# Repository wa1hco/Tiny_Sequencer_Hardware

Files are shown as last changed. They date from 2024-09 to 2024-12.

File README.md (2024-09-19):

# Tiny_Sequencer_Hardware
Schematic, Layout, and component files  
KiCad V8 used for schematic and layout  
ATTiny814 microcontroller  
FTDI230 Serial interface  
Surface mount components  
Back side is grouind plane, a few jumpers, and no components  
Connections via 12 pin screw terminal header with 0.1 inch spacing  
- 4 contact closure outputs using AC/DC optoisolators  
- Key input with return
- 6 to 30V DC input and return

Powered by DC or USB  
Programming via UPDI over USB  
Software able to use serial port for communication  
Status LEDs
- 4 sequencer ouptuts,
- 5V,
- Tx serial activity
- Rx serial activity

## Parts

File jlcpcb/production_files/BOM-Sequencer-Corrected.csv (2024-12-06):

Comment | Designator | Footprint | LCSC | Quantity | Description
47p | C1,C5 | C_0603_1608Metric | C1671 | 2 | 50V 47pF C0G ±5% 0603 Multilayer Ceramic Capacitors
6.8u | C2 | C_0603_1608Metric | C338096 | 1 | 10V 6.8uF X5R ±10% 0603 Multilayer Ceramic Capacitors
.1u | C3,C4,C6,C7,C8,C9 | C_0603_1608Metric | C14663 | 5 | 50V 100nF X7R ±10% 0603 Multilayer Ceramic Capacitors
0.33u | C4 | C_0603_1608Metric | C292682 |  | 50V 330nF X7R ±10% 0603 Multilayer Ceramic Capacitors
Red | D1,D2,D3,D4 | LED_0603_1608Metric | C2286 | 4 | -40℃~+85℃ Red 0603 LED Indication
D_Schottky | D10 | D_0603_1608Metric | C143772 | 1 | 40V 450mV@200mA 200mA 0603 Schottky Diodes
MM3Z3V6 | D11,D12,D5 | D_SOD-323 | C891617 | 3 | Independent Type 3.42V~3.78V 200mW 3.6V SOD-323FL Zener Diodes
Green | D6,D7,D8,D9 | LED_0603_1608Metric | C965806 | 4 | 20mA 240mcd 565nm~575nm -20℃~+85℃ Positive Stick Yellow Green 120° 50mW 2.4V 0603 LED
FerriteBead_Small | FB1 | L_0805_2012Metric | C1017 | 1 | 300mΩ ±25% 600Ω@100MHz 0805 Ferrite Beads
Screw_Terminal_01x12 | J1 | TerminalBlock_TE_1-282834-2_1x12_P2.54mm_Horizontal | C5188451 | 1 | Copper Alloy 1x12P Tin 2.54mm 1 1 12 6A -40℃~+105℃ 150V Green 18~24
Header 1x3 | J2 | PinHeader_1x03_P2.54mm_Vertical | C6332196 | 1 | Gold 250V 3A 2.54mm 3P 6mm -40℃~+105℃ 3mm 2.54mm Brass Black Single
USB-C 2.0 16P | J3 | USB_C_Receptacle_G-Switch_GT-USB-7010ASV | C2988369 | 1 | USB 2.0 3A 1 Horizontal attachment 16P Female -40℃~+85℃ Gold Type-C
Conn_01x08_Pin | J4 | PinHeader_1x08_P2.54mm_Vertical | C18078205 | 1 | Gold 1kV 3A 2.5mm 8P 6mm -40℃~+105℃ 3mm 2.54mm Brass Black Single Row 1x8PPin Headers
1K5 | R1,R2,R3,R4 | R_0603_1608Metric | C22843 | 4 | 100mW Thick Film Resistors 75V ±100ppm/℃ ±1% 1.5kΩ 0603 Chip Resistor
1K5 | R5,R6,R7,R8 | R_0603_1608Metric | C23193 | 4 | 100mW Thick Film Resistors 75V ±100ppm/℃ ±1% 510Ω 0603 Chip Resistor
1K | R10,R11,R12,R15,R16,R17,R20 | R_0603_1608Metric | C21190 | 7 | 100mW Thick Film Resistors 75V ±100ppm/℃ ±1% 1kΩ 0603 Chip Resistor
27R | R13,R14,R18,R19 | R_0603_1608Metric | C25190 | 2 | 100mW Thick Film Resistors 75V ±1% ±200ppm/℃ 27Ω 0603 Chip Resistor
5K1 | R18, R19 | R_0603_1608Metric | C23186 | 2 | 100mW Thick Film Resistors 75V ±100ppm/℃ ±1% 5.1kΩ 0603 Chip Resistor
2K2 | R9 | R_0603_1608Metric | C4190 | 1 | 100mW Thick Film Resistors 75V ±100ppm/℃ ±1% 2.2kΩ 0603 Chip Resistor
GAQY212G2S | U2,U3,U4,U5 | SO-4_4.4x3.9mm_P2.54mm | C7435109 | 4 | 1 Form A(SPST-NO) 1.2V 60V 68mΩ 1.8A SOP-4 Solid State Relays (MOS Output)
MC78L05_SOT89 | U6 | SOT-89-3 | C71136 | 1 | 100mA Fixed 5V Positive electrode 30V SOT-89-3 Voltage Regulators
FT230XS | U7 | SSOP-16_3.9x4.9mm_P0.635mm | C69082 | 1 | USB to UART UART SSOP-16-150mil USB Converters
TLP185 | U8 | SOIC-4_4.55x3.7mm_P2.54mm | C17695768 | 1 | 3.75kV 50mA 1 1.25V SOIC-4-175mil Transistor, Photovoltaic Output Optoisolators
ATtiny1616-M | U9 | VQFN-20-1EP_3x3mm_P0.4mm_EP1.7x1.7mm | C507118 | 1 | 16KB 1.8V~5.5V AVR 2KB 20MHz FLASH 18 QFN-20-EP(3x3) Microcontrollers

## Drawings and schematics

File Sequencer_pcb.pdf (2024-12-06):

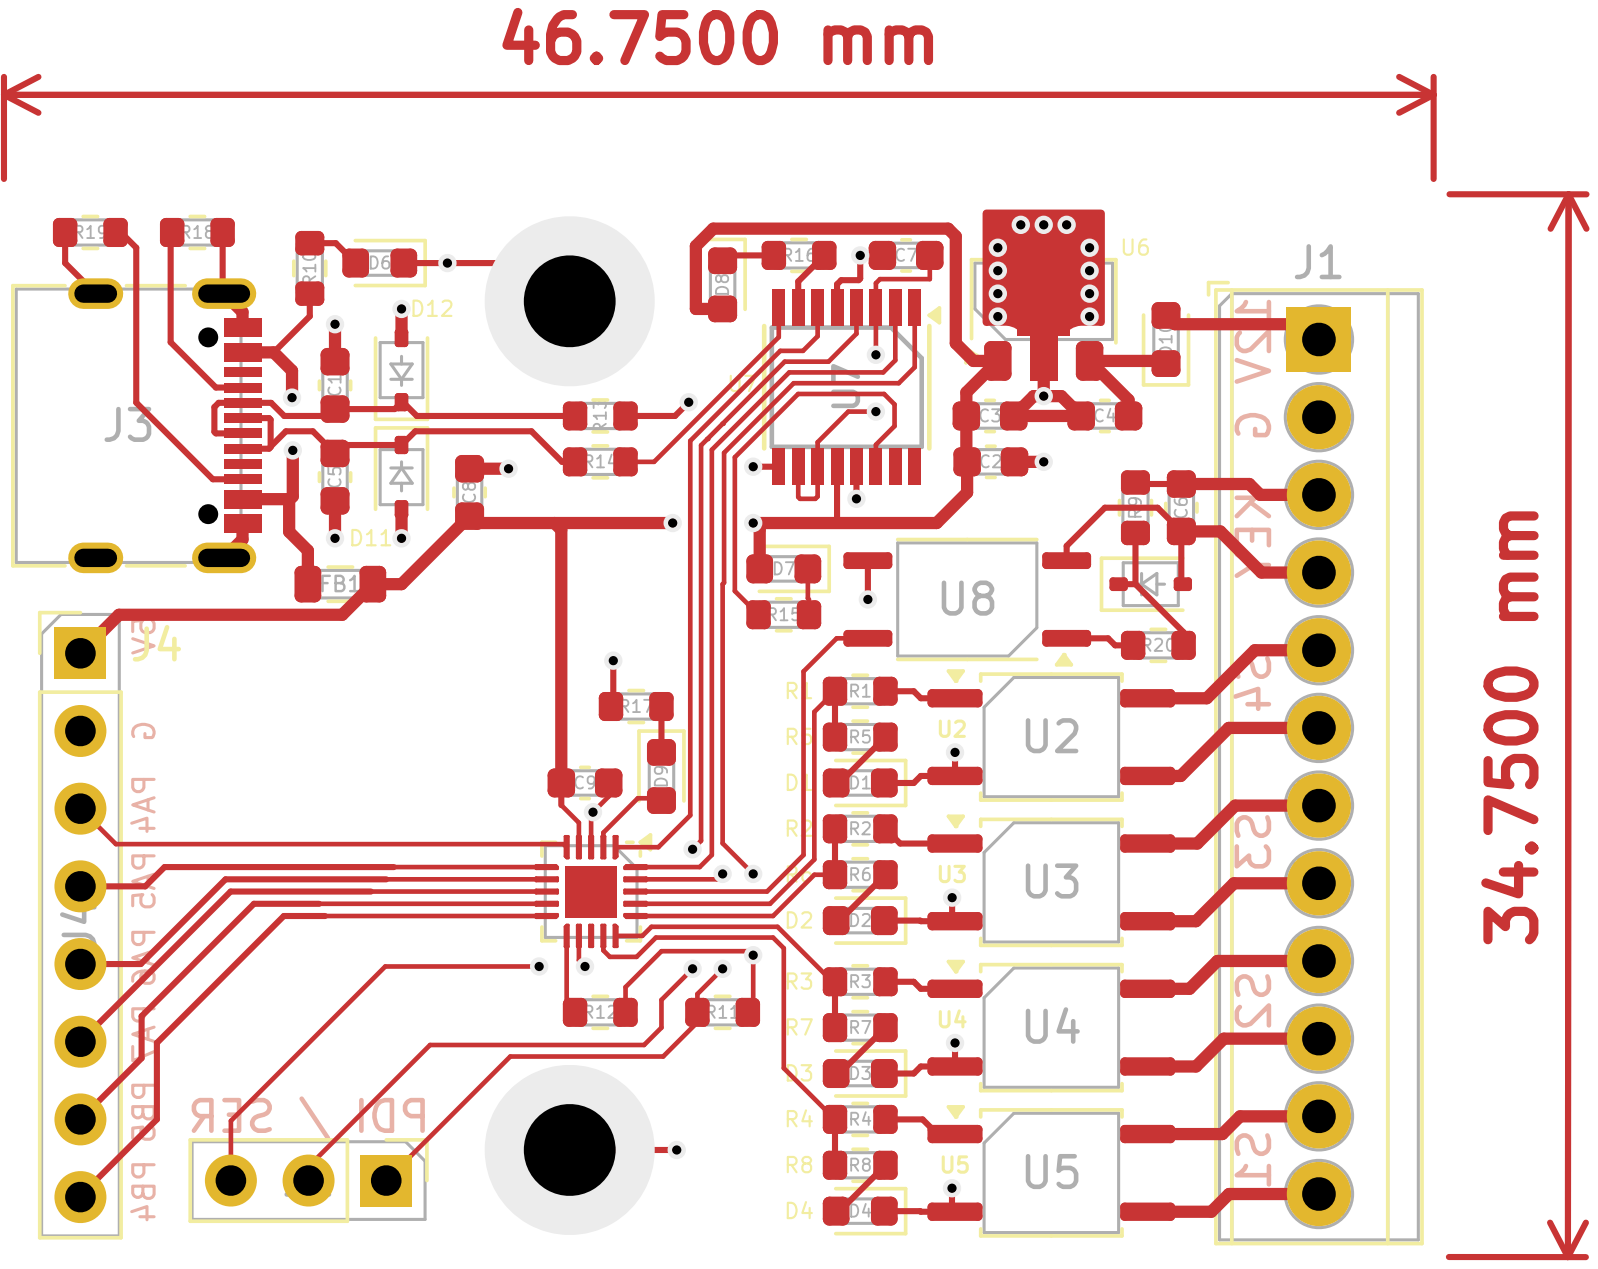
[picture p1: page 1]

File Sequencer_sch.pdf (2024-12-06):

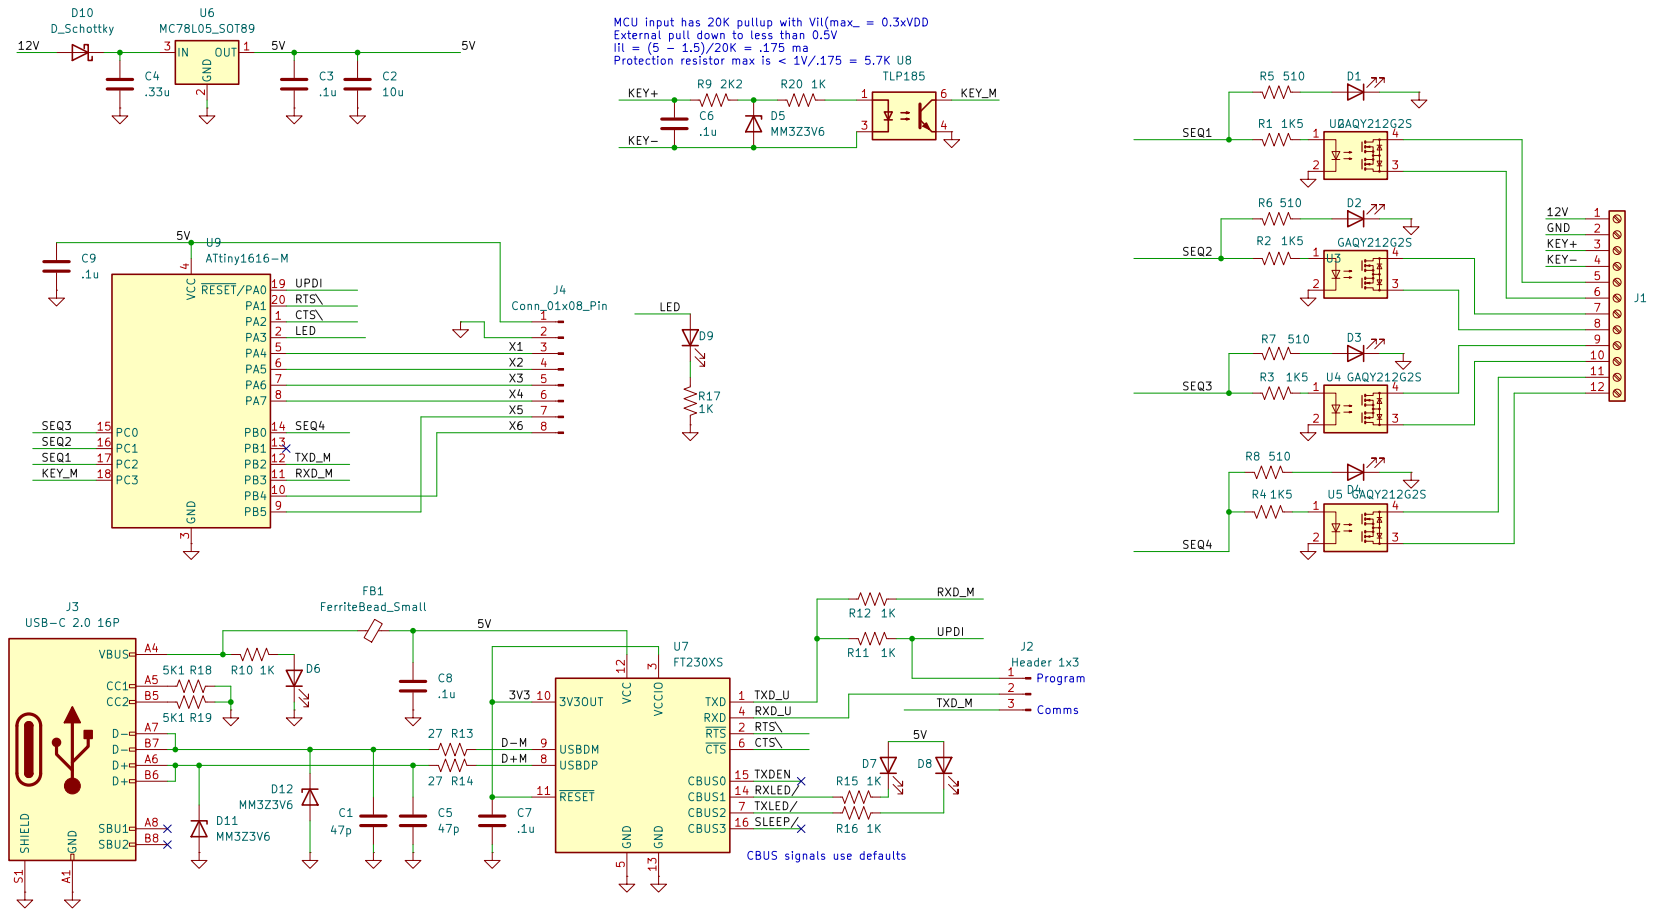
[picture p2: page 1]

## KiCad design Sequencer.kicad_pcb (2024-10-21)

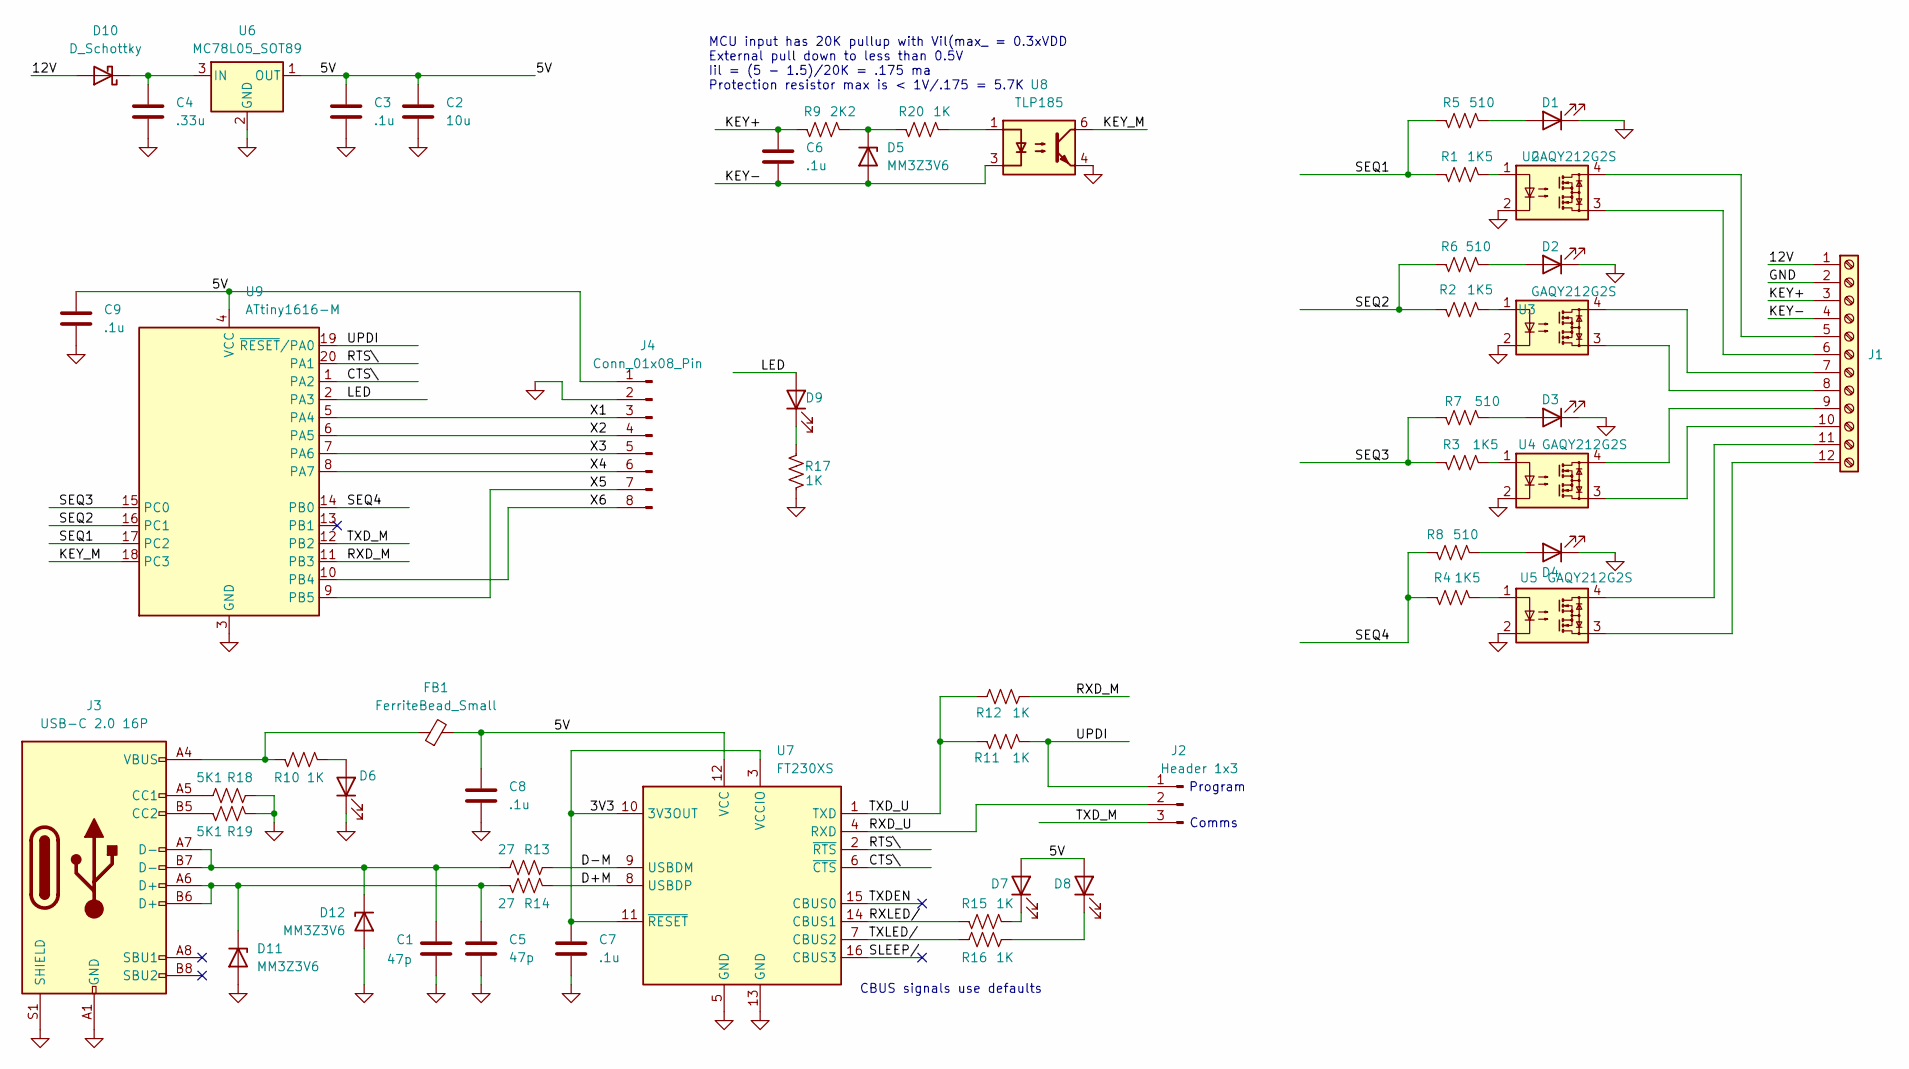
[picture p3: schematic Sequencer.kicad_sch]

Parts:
C1, C5: 47p; C_0603_1608Metric; LCSC PN C1671
C2: 10u; C_0603_1608Metric; LCSC PN C19702
C3, C6, C7, C8, C9: .1u; C_0603_1608Metric; LCSC PN C15849
C4: .33u; C_0603_1608Metric; LCSC PN C2918485
D1, D2, D3, D4: Red; LED_0603_1608Metric; LCSC PN C2286
D5, D11, D12: MM3Z3V6; D_SOD-323; LCSC PN C19077454
D6, D9: Green; LED_0603_1608Metric; LCSC PN C22371299
D7, D8: Yellow; LED_0603_1608Metric; LCSC PN C72038
D10: D_Schottky; D_0603_1608Metric; LCSC PN C143772
FB1: FerriteBead_Small; L_0805_2012Metric; LCSC PN C1017
J1: Screw_Terminal_01x12; TerminalBlock_TE_1-282834-2_1x12_P2.54mm_Horizontal; LCSC PN C474929
J2: Header 1x3; PinHeader_1x03_P2.54mm_Vertical; LCSC PN C6332196
J3: USB-C 2.0 16P; USB_C_Receptacle_G-Switch_GT-USB-7010ASV; LCSC PN C2835315
J4: Conn_01x08_Pin; PinHeader_1x08_P2.54mm_Vertical; LCSC PN C18078205
R1, R2, R3, R4: 1K5; R_0603_1608Metric; LCSC PN C22843
R5, R6, R7, R8: 510; R_0603_1608Metric; LCSC PN C23193
R9: 2K2; R_0603_1608Metric; LCSC PN C4190
R10, R11, R12, R15, R16, R17, R20: 1K; R_0603_1608Metric; LCSC PN C21190
R13, R14: 27; R_0603_1608Metric; LCSC PN C25190
R18, R19: 5K1; R_0603_1608Metric; LCSC PN C23186
U2, U3, U4, U5: GAQY212G2S; SO-4_4.4x3.9mm_P2.54mm; LCSC PN C7435109
U6: MC78L05_SOT89; SOT-89-3; LCSC PN C5346137
U7: FT230XS; SSOP-16_3.9x4.9mm_P0.635mm; LCSC PN C69082
U8: TLP185; SOIC-4_4.55x3.7mm_P2.54mm; LCSC PN C17695768
U9: ATtiny1616-M; VQFN-20-1EP_3x3mm_P0.4mm_EP1.7x1.7mm

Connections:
/3V3: C7.1, U7.3 (VCCIO), U7.10 (3V3OUT), U7.11 (~RESET)
/5V: C2.1, C3.1, C8.1, C9.1, D7.2 (A), D8.2 (A), FB1.2, J4.1, U6.1 (OUT), U7.12 (VCC), U9.4 (VCC)
/12V: D10.2 (A), J1.1
/CTS\: U7.6 (~CTS), U9.1 (PA2)
/D+M: R14.1, U7.8 (USBDP)
/D-M: R13.1, U7.9 (USBDM)
/KEY+: C6.1, J1.3, R9.1
/KEY-: C6.2, D5.2 (A), J1.4, U8.3
/KEY_M: U8.6, U9.18 (PC3)
/LED: D9.2 (A), U9.2 (PA3)
/RTS\: U7.2 (~RTS), U9.20 (PA1)
/RXD_M: R12.2, U9.11 (PB3)
/RXD_U: J2.2, U7.4 (RXD)
/RXLED/: R15.1, U7.14 (CBUS1)
/SEQ1: R1.1, R5.1, U9.17 (PC2)
/SEQ2: R2.1, R6.1, U9.16 (PC1)
/SEQ3: R3.1, R7.1, U9.15 (PC0)
/SEQ4: R4.1, R8.1, U9.14 (PB0)
/SLEEP/: U7.16 (CBUS3)
/TXDEN: U7.15 (CBUS0)
/TXD_M: J2.3, U9.12 (PB2)
/TXD_U: R11.1, R12.1, U7.1 (TXD)
/TXLED/: R16.1, U7.7 (CBUS2)
/UPDI: J2.1, R11.2, U9.19 (~RESET/PA0)
/X1: J4.3, U9.5 (PA4)
/X2: J4.4, U9.6 (PA5)
/X3: J4.5, U9.7 (PA6)
/X4: J4.6, U9.8 (PA7)
/X5: J4.7, U9.9 (PB5)
/X6: J4.8, U9.10 (PB4)
GND: C1.2, C2.2, C3.2, C4.2, C5.2, C7.2, C8.2, C9.2, D1.1 (K), D2.1 (K), D3.1 (K), D4.1 (K), D6.1 (K), D11.2 (A), D12.2 (A), J1.2, J3.A1 (GND), J3.A12 (GND), J3.B1 (GND), J3.B12 (GND), J3.S1 (SHIELD), J4.2, R17.2, R18.1, R19.1, U2.2, U3.2, U4.2, U5.2, U6.2 (GND), U7.5 (GND), U7.13 (GND), U8.4, U9.3 (GND), U9.21 (GND)
unnamed: D1.2 (A), R5.2
unnamed: D2.2 (A), R6.2
unnamed: D3.2 (A), R7.2
unnamed: D4.2 (A), R8.2
unnamed: D5.1 (K), R9.2, R20.1
unnamed: D6.2 (A), R10.1
unnamed: D7.1 (K), R15.2
unnamed: D8.1 (K), R16.2
unnamed: D9.1 (K), R17.1
unnamed: C4.1, D10.1 (K), U6.3 (IN)
unnamed: C5.1, D11.1 (K), J3.A6 (D+), J3.B6 (D+), R14.2
unnamed: C1.1, D12.1 (K), J3.A7 (D-), J3.B7 (D-), R13.2
unnamed: FB1.1, J3.A4 (VBUS), J3.A9 (VBUS), J3.B4 (VBUS), J3.B9 (VBUS), R10.2
unnamed: J1.5, U2.4
unnamed: J1.6, U2.3
unnamed: J1.7, U3.4
unnamed: J1.8, U3.3
unnamed: J1.9, U4.4
unnamed: J1.10, U4.3
unnamed: J1.11, U5.4
unnamed: J1.12, U5.3
unnamed: J3.A5 (CC1), R18.2
unnamed: J3.B5 (CC2), R19.2
unnamed: R1.2, U2.1
unnamed: R2.2, U3.1
unnamed: R3.2, U4.1
unnamed: R4.2, U5.1
unnamed: R20.2, U8.1

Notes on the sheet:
CBUS signals use defaults
MCU input has 20K pullup with Vil(max_ = 0.3xVDD External pull down to less than 0.5V Iil = (5 - 1.5)/20K = .175 ma Protection resistor max is < 1V/.175 = 5.7K
Program
Comms

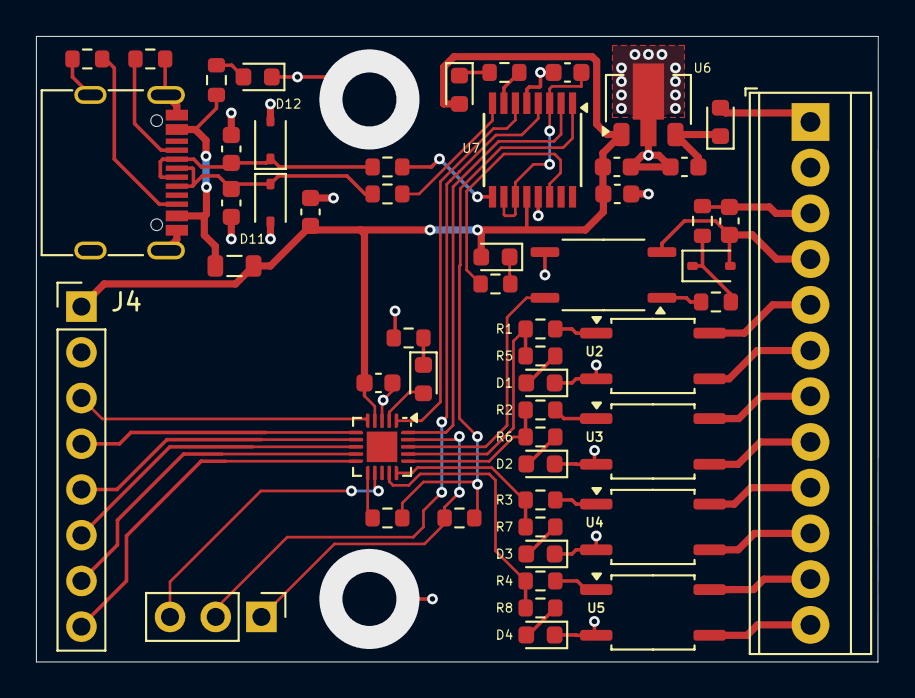
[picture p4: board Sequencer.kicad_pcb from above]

Board: 2 copper layers, 46.8 x 34.8 mm, 54 parts (0 on the bottom side), 57 nets.

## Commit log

2024-09-19 Sequencer schematic and partial pcb layout
    [Sequencer.kicad_pcb, Sequencer.kicad_sch]
2024-09-19 Added MCU controlled LED Changed bottom fill to cover two resistors
    [Sequencer.kicad_pcb, Sequencer.kicad_sch]
2024-09-21 Converted to USB-C connector Added zener protection to USB data wires Shuffled layout to reduce jumpers Generated BOM and gerbers for experimenting with JLCPCB
    [JLCPCB_BOM.xls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]
2024-09-23 middle of trying to remove some jumpers and make wiring more direct Trying to create room for reverse polarity protection on 12V
    [Sequencer.kicad_pcb, Sequencer.kicad_sch]
2024-10-10 Added optocoupler on KEY line Changed to ATTinyx16 processor with 20 pins Serial select for UPDI vs Serial comms is now a pin header Added pin header for other unused signals on MCU
    [Sequencer.kicad_pcb, Sequencer.kicad_sch]
2024-10-17 small schematic rearrangement
    [Sequencer.kicad_pcb, Sequencer.kicad_sch]
2024-10-20 Finalized design for release to JCLPCB Add terminal block library Added some data sheets for terminal block, USB-C connector, etc
    [Sequencer.kicad_pcb, Sequencer.kicad_sch]
2024-10-21 Added USB-C connector footprints Changed ATTiny from SOIC-20 to 3x3 mm QFP
    [Sequencer.kicad_pcb, Sequencer.kicad_sch]
2024-10-21 removed previous gerber and other prodution files added jlcpcb related production files update license to cc BY-SA 4.0
    [BOM-Sequencer.csv, JLCPCB_BOM.xls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]
2024-12-06 This records the status of the board after fixing component values from first build. Sent this to JLCPCB, but they found and error in FT230 package selection. Parts availability says it needs to chan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
    [BOM-Sequencer-Corrected.csv, BOM_from_KiCAD.csv, bom_SMT024102160181-Y3.xls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]
2024-12-07 These files were used for the JLCPCB Y7 build, Dec 6, 2024
    [Sequencer-top-pos.xls]
